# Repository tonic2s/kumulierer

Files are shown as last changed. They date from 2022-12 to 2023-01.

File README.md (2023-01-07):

# Kumulierer
## Description
Li-Ion battery charger with basic protection, usb-c input / 2-pin output &amp; power path

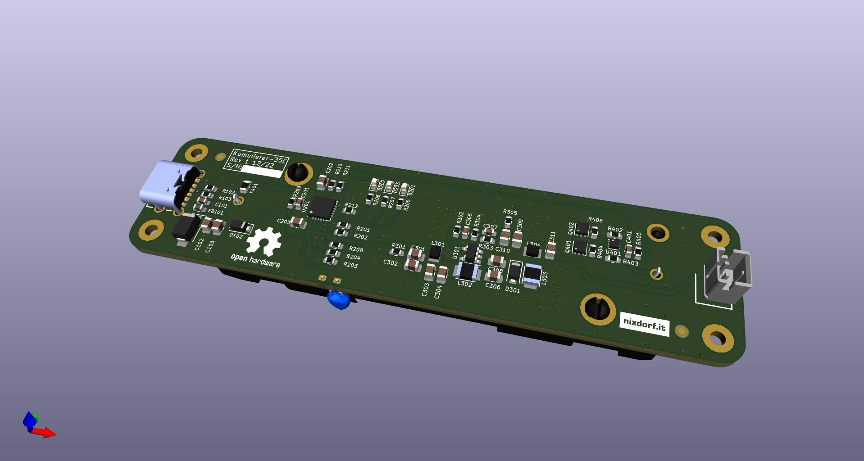
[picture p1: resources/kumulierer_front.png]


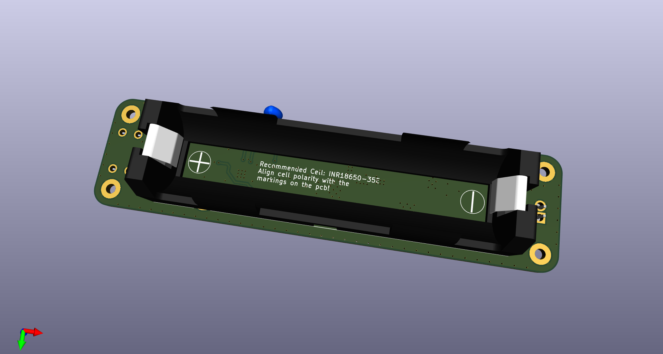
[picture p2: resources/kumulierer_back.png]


## Links
[Aisler Project](https://aisler.net/p/CNVPTRAD)

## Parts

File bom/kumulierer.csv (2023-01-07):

Source: | C:\Users\nixdo\Documents\E-Technik\kumulierer\kicad\kumulierer.kicad_sch
Date: | 07.01.2023 17:58:50
Tool: | Eeschema (6.0.6)
Generator: | C:\Program Files\KiCad\6.0\bin\scripting\plugins/bom_csv_grouped_by_value.py
Component Count: | 74
Individual Components:
Item | Qty | Reference(s) | Value | LibPart | Footprint | Datasheet | Mouser Part Nr.
 |  | BT401 | 18650-35E | Device:Battery_Cell | Parts_Library:1043_Battery_holder_18650 | https://www.mouser.de/datasheet/2/215/1043-745411.pdf | 534-1043
 |  | C101 | 100n | Device:C_Small | Capacitor_SMD:C_0603_1608Metric | https://www.mouser.de/datasheet/2/585/MLCC_Automotive-1837966.pdf | 187-CL10B104KO8WPNC
 |  | C102 | 10u | Device:C_Small | Capacitor_SMD:C_0805_2012Metric | https://www.mouser.de/datasheet/2/585/MLCC-1837944.pdf | 187-CL21A106KOQNNNE
 |  | C103 | 10u | Device:C_Small | Capacitor_SMD:C_0805_2012Metric | https://www.mouser.de/datasheet/2/585/MLCC-1837944.pdf | 187-CL21A106KOQNNNE
 |  | C201 | 100n | Device:C_Small | Capacitor_SMD:C_0603_1608Metric | https://www.mouser.de/datasheet/2/585/MLCC_Automotive-1837966.pdf | 187-CL10B104KO8WPNC
 |  | C202 | 10u | Device:C_Small | Capacitor_SMD:C_0805_2012Metric | https://www.mouser.de/datasheet/2/585/MLCC-1837944.pdf | 187-CL21A106KOQNNNE
 |  | C203 | 10u | Device:C_Small | Capacitor_SMD:C_0805_2012Metric | https://www.mouser.de/datasheet/2/585/MLCC-1837944.pdf | 187-CL21A106KOQNNNE
 |  | C301 | 10u | Device:C_Small | Capacitor_SMD:C_0805_2012Metric | https://www.mouser.de/datasheet/2/585/MLCC-1837944.pdf | 187-CL21A106KOQNNNE
 |  | C302 | 10u | Device:C_Small | Capacitor_SMD:C_0805_2012Metric | https://www.mouser.de/datasheet/2/585/MLCC-1837944.pdf | 187-CL21A106KOQNNNE
 |  | C303 | 10u | Device:C_Small | Capacitor_SMD:C_0805_2012Metric | https://www.mouser.de/datasheet/2/585/MLCC-1837944.pdf | 187-CL21A106KOQNNNE
 |  | C304 | 10u | Device:C_Small | Capacitor_SMD:C_0805_2012Metric | https://www.mouser.de/datasheet/2/585/MLCC-1837944.pdf | 187-CL21A106KOQNNNE
 |  | C305 | 100n | Device:C_Small | Capacitor_SMD:C_0603_1608Metric | https://www.mouser.de/datasheet/2/585/MLCC_Automotive-1837966.pdf | 187-CL10B104KO8WPNC
 |  | C306 | 10u | Device:C_Small | Capacitor_SMD:C_0805_2012Metric | https://www.mouser.de/datasheet/2/585/MLCC-1837944.pdf | 187-CL21A106KOQNNNE
 |  | C307 | 1n | Device:C_Small | Capacitor_SMD:C_0603_1608Metric | https://www.mouser.de/datasheet/2/585/MLCC-1837944.pdf | 187-CL10C102JB8NNND
 |  | C308 | 10u | Device:C_Small | Capacitor_SMD:C_0805_2012Metric | https://www.mouser.de/datasheet/2/585/MLCC-1837944.pdf | 187-CL21A106KOQNNNE
 |  | C309 | 10u | Device:C_Small | Capacitor_SMD:C_0805_2012Metric | https://www.mouser.de/datasheet/2/585/MLCC-1837944.pdf | 187-CL21A106KOQNNNE
 |  | C310 | 10u | Device:C_Small | Capacitor_SMD:C_0805_2012Metric | https://www.mouser.de/datasheet/2/585/MLCC-1837944.pdf | 187-CL21A106KOQNNNE
 |  | C311 | 10u | Device:C_Small | Capacitor_SMD:C_0805_2012Metric | https://www.mouser.de/datasheet/2/585/MLCC-1837944.pdf | 187-CL21A106KOQNNNE
 |  | C401 | 100n | Device:C_Small | Capacitor_SMD:C_0603_1608Metric | https://www.mouser.de/datasheet/2/585/MLCC_Automotive-1837966.pdf | 187-CL10B104KO8WPNC
 |  | D101 | SMA 5V | Device:D_Zener_Small | Diode_SMD:D_SMA | https://www.diodes.com/assets/Datasheets/ds18015.pdf | 621-SMAZ5V6-F
 |  | D102 | ACDBMS240-HF | Device:D_Schottky_Small | Diode_SMD:D_SOD-123F | https://www.mouser.de/datasheet/2/80/12030_20190322133442-2933606.pdf | 750-ACDBMS240-HF
 |  | D201 | RED | Device:LED_Small | LED_SMD:LED_0603_1608Metric | https://www.mouser.de/datasheet/2/445/150060RS75000-1715052.pdf | 710-150060RS75000
 |  | D202 | RED | Device:LED_Small | LED_SMD:LED_0603_1608Metric | https://www.mouser.de/datasheet/2/445/150060RS75000-1715052.pdf | 710-150060RS75000
 |  | D203 | RED | Device:LED_Small | LED_SMD:LED_0603_1608Metric | https://www.mouser.de/datasheet/2/445/150060RS75000-1715052.pdf | 710-150060RS75000
 |  | D301 | ACDBMS240-HF | Device:D_Schottky_Small | Diode_SMD:D_SOD-123F | https://www.mouser.de/datasheet/2/80/12030_20190322133442-2933606.pdf | 750-ACDBMS240-HF
 |  | F101 | 500mA 1206 | Device:Polyfuse_Small | Fuse:Fuse_1206_3216Metric | https://www.mouser.de/datasheet/2/447/SMD1206_1-1954982.pdf | 603-SMD1206B050TF/15
 |  | F401 | 6A | Device:Fuse_Small | Fuse:Fuse_0805_2012Metric | https://www.mouser.de/datasheet/2/643/ds-CP-c2f-series-1291054.pdf | 530-0686F6000-01
 |  | FB101 | 220 | Device:FerriteBead_Small | Inductor_SMD:L_0603_1608Metric | https://www.mouser.de/datasheet/2/54/mh-777565.pdf | 652-MH1608-221Y
 |  | FID101 | Fiducial | Mechanical:Fiducial | Fiducial:Fiducial_1mm_Mask2mm | ~
 |  | FID102 | Fiducial | Mechanical:Fiducial | Fiducial:Fiducial_1mm_Mask2mm | ~
 |  | H101 | M2 | Mechanical:MountingHole_Pad | MountingHole:MountingHole_2.2mm_M2_Pad | ~
 |  | H102 | M2 | Mechanical:MountingHole_Pad | MountingHole:MountingHole_2.2mm_M2_Pad | ~
 |  | H103 | M2 | Mechanical:MountingHole_Pad | MountingHole:MountingHole_2.2mm_M2_Pad | ~
 |  | H104 | M2 | Mechanical:MountingHole_Pad | MountingHole:MountingHole_2.2mm_M2_Pad | ~
 |  | J101 | USB4125-GF-A | Connector:USB_C_Receptacle_USB2.0 | Parts_Library:USB4125GFA | https://www.mouser.de/datasheet/2/837/USB4125-2888141.pdf | 640-USB4125-GF-A
 |  | J102 | 6-440054-2 | Connector_Generic:Conn_01x02 | Parts_Library:6-440054-2 2 Pin Header | https://www.te.com/commerce/DocumentDelivery/DDEController?Action=srchrtrv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 | 6-440054-2
 |  | L301 | 470nH | Device:L_Small | Parts_Library:IND_0806_2016 | https://www.mouser.de/datasheet/2/396/wound10_e-1396630.pdf | 963-MAKK2016TR47M
 |  | L302 | 3.3uH | Device:L_Small | Inductor_SMD:L_TDK_NLV32_3.2x2.5mm | https://www.mouser.de/datasheet/2/54/SRP3212A-3011944.pdf | 652-SRP3212A-3R3M
 |  | L303 | 3.3uH | Device:L_Small | Inductor_SMD:L_TDK_NLV32_3.2x2.5mm | https://www.mouser.de/datasheet/2/54/SRP3212A-3011944.pdf | 652-SRP3212A-3R3M
 |  | L304 | 470nH | Device:L_Small | Parts_Library:IND_0806_2016 | https://www.mouser.de/datasheet/2/396/wound10_e-1396630.pdf | 963-MAKK2016TR47M
 |  | Q401 | CSD17313Q2 | Transistor_FET:CSD17313Q2 | Package_SON:Texas_DQK | http://www.ti.com/lit/ds/symlink/csd17313q2.pdf | 595-CSD17313Q2
 |  | Q402 | CSD17313Q2 | Transistor_FET:CSD17313Q2 | Package_SON:Texas_DQK | http://www.ti.com/lit/ds/symlink/csd17313q2.pdf | 595-CSD17313Q2
 |  | R102 | 5k1 | Device:R_Small | Resistor_SMD:R_0603_1608Metric | https://www.mouser.de/datasheet/2/447/PYu_RC_Group_51_RoHS_L_11-1984063.pdf | 603-RC0603JR-075K1L
 |  | R103 | 5k1 | Device:R_Small | Resistor_SMD:R_0603_1608Metric | https://www.mouser.de/datasheet/2/447/PYu_RC_Group_51_RoHS_L_11-1984063.pdf | 603-RC0603JR-075K1L
 |  | R201 | 0 | Device:R_Small | Resistor_SMD:R_0603_1608Metric | https://www.mouser.de/datasheet/2/447/PYu_RC_Group_51_RoHS_L_11-1984063.pdf | 603-RC0603JR-070RL
 |  | R202 | 0 | Device:R_Small | Resistor_SMD:R_0603_1608Metric | https://www.mouser.de/datasheet/2/447/PYu_RC_Group_51_RoHS_L_11-1984063.pdf | 603-RC0603JR-070RL
 |  | R203 | 330k | Device:R_Small | Resistor_SMD:R_0603_1608Metric | https://www.mouser.de/datasheet/2/447/PYu_RC_Group_51_RoHS_L_11-1984063.pdf | 603-RC0603FR-13330KL
 |  | R204 | 110k | Device:R_Small | Resistor_SMD:R_0603_1608Metric | https://www.mouser.de/datasheet/2/447/PYu_RC_Group_51_RoHS_L_11-1984063.pdf | 603-RC0603JR-13110KL
 |  | R205 | 1k | Device:R_Small | Resistor_SMD:R_0603_1608Metric | https://www.mouser.de/datasheet/2/447/PYu_RC_Group_51_RoHS_L_11-1984063.pdf | 603-RC0603JR-071KL
 |  | R206 | 1k | Device:R_Small | Resistor_SMD:R_0603_1608Metric | https://www.mouser.de/datasheet/2/447/PYu_RC_Group_51_RoHS_L_11-1984063.pdf | 603-RC0603JR-071KL
 |  | R207 | 1k | Device:R_Small | Resistor_SMD:R_0603_1608Metric | https://www.mouser.de/datasheet/2/447/PYu_RC_Group_51_RoHS_L_11-1984063.pdf | 603-RC0603JR-071KL
 |  | R208 | 1k | Device:R_Small | Resistor_SMD:R_0603_1608Metric | https://www.mouser.de/datasheet/2/447/PYu_RC_Group_51_RoHS_L_11-1984063.pdf | 603-RC0603JR-071KL
 |  | R209 | 1k | Device:R_Small | Resistor_SMD:R_0603_1608Metric | https://www.mouser.de/datasheet/2/447/PYu_RC_Group_51_RoHS_L_11-1984063.pdf | 603-RC0603JR-071KL
 |  | R210 | 2k2 | Device:R_Small | Resistor_SMD:R_0603_1608Metric | https://www.mouser.de/datasheet/2/447/PYu_RC_Group_51_RoHS_L_11-1984063.pdf | 603-RC0603FR-072K2L
 |  | R211 | 22k | Device:R_Small | Resistor_SMD:R_0603_1608Metric | https://www.mouser.de/datasheet/2/447/PYu_RC_Group_51_RoHS_L_11-1984063.pdf | 603-RC0603JR-0722KL
 |  | R212 | 1k | Device:R_Small | Resistor_SMD:R_0603_1608Metric | https://www.mouser.de/datasheet/2/447/PYu_RC_Group_51_RoHS_L_11-1984063.pdf | 603-RC0603JR-071KL
 |  | R213 | 1k | Device:R_Small | Resistor_SMD:R_0603_1608Metric | https://www.mouser.de/datasheet/2/447/PYu_RC_Group_51_RoHS_L_11-1984063.pdf | 603-RC0603JR-071KL
 |  | R214 | 10k | Device:R_Small | Resistor_SMD:R_0603_1608Metric | https://www.mouser.de/datasheet/2/447/PYu_RC_Group_51_RoHS_L_11-1984063.pdf | 603-RC0603FR-0710KL
 |  | R301 | 1 | Device:R_Small | Resistor_SMD:R_0603_1608Metric | https://www.mouser.de/datasheet/2/447/PYu_RC_Group_51_RoHS_L_11-1984063.pdf | 603-RC0603JR-071RL
 |  | R302 | 10k | Device:R_Small | Resistor_SMD:R_0603_1608Metric | https://www.mouser.de/datasheet/2/447/PYu_RC_Group_51_RoHS_L_11-1984063.pdf | 603-RC0603FR-0710KL
 |  | R303 | 30k | Device:R_Small | Resistor_SMD:R_0603_1608Metric | https://www.mouser.de/datasheet/2/315/AOA0000C304-1149620.pdf | 667-ERJ-3EKF3002V
 |  | R304 | 10k | Device:R_Small | Resistor_SMD:R_0603_1608Metric | https://www.mouser.de/datasheet/2/447/PYu_RC_Group_51_RoHS_L_11-1984063.pdf | 603-RC0603FR-0710KL
 |  | R305 | 1 | Device:R_Small | Resistor_SMD:R_0603_1608Metric | https://www.mouser.de/datasheet/2/447/PYu_RC_Group_51_RoHS_L_11-1984063.pdf | 603-RC0603JR-071RL
 |  | R306 | 1M | Device:R_Small | Resistor_SMD:R_0603_1608Metric | https://www.mouser.de/datasheet/2/447/PYu_RC_Group_51_RoHS_L_11-1984063.pdf | 603-RC0603FR-071ML
 |  | R401 | 330 | Device:R_Small | Resistor_SMD:R_0603_1608Metric | https://www.mouser.de/datasheet/2/447/PYu_RC_Group_51_RoHS_L_11-1984063.pdf | 603-RC0603FR-13330RL
 |  | R402 | 2k2 | Device:R_Small | Resistor_SMD:R_0603_1608Metric | https://www.mouser.de/datasheet/2/447/PYu_RC_Group_51_RoHS_L_11-1984063.pdf | 603-RC0603FR-072K2L
 |  | R403 | 0 | Device:R_Small | Resistor_SMD:R_0603_1608Metric | https://www.mouser.de/datasheet/2/447/PYu_RC_Group_51_RoHS_L_11-1984063.pdf | 603-RC0603JR-070RL
 |  | R404 | 5.1M | Device:R_Small | Resistor_SMD:R_0603_1608Metric | https://www.mouser.de/datasheet/2/447/PYu_AC_51_RoHS_L_9-3005297.pdf | 603-AC0603FR-075M1L
 |  | R405 | 5.1M | Device:R_Small | Resistor_SMD:R_0603_1608Metric | https://www.mouser.de/datasheet/2/447/PYu_AC_51_RoHS_L_9-3005297.pdf | 603-AC0603FR-075M1L
 |  | SW101 | DS04-254-2-02BK-SMT | Switch:SW_DIP_x02 | Footprints:SW_DS04-254-2-02BK-SMT | https://www.mouser.de/datasheet/2/670/ds04_254_smt-1777718.pdf | 490-DS04254202BK-SMT
 |  | TH201 | 10k | Device:Thermistor_NTC | Parts_Library:NRL1104J3380B1F | https://www.eaton.com/content/dam/eaton/products/electronic-components/resources/data-sheet/eaton-nrl-epoxy-sealed-radial-lead-ntc-thermistor-data-sheet-elx11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 | 504-NRL1104J3380B1F
 |  | U201 | MCP73871-2CC | Battery_Management:MCP73871-2CC | Package_DFN_QFN:QFN-20-1EP_4x4mm_P0.5mm_EP2.5x2.5mm | http://www.mouser.com/ds/2/268/22090a-52174.pdf
 |  | U301 | LMR62421XMF | Regulator_Switching:LMR62421XMF | Package_TO_SOT_SMD:SOT-23-5 | http://www.ti.com/lit/ds/symlink/lmr62421.pdf
 |  | U401 | BQ29717 | Battery_Management:BQ297xy | Package_SON:WSON-6_1.5x1.5mm_P0.5mm | http://www.ti.com/lit/ds/symlink/bq2970.pdf | 595-BQ29717DSER
Collated Components:
Item | Qty | Reference(s) | Value | LibPart | Footprint | Datasheet | Mouser Part Nr.
1 | 1 | BT401 | 18650-35E | Device:Battery_Cell | Parts_Library:1043_Battery_holder_18650 | https://www.mouser.de/datasheet/2/215/1043-745411.pdf | 534-1043
2 | 4 | C101, C201, C305, C401 | 100n | Device:C_Small | Capacitor_SMD:C_0603_1608Metric | https://www.mouser.de/datasheet/2/585/MLCC_Automotive-1837966.pdf | 187-CL10B104KO8WPNC
3 | 13 | C102, C103, C202, C203, C301, C302, C303, C304, C306, C308, C309, C310, C311 | 10u | Device:C_Small | Capacitor_SMD:C_0805_2012Metric | https://www.mouser.de/datasheet/2/585/MLCC-1837944.pdf | 187-CL21A106KOQNNNE
4 | 1 | C307 | 1n | Device:C_Small | Capacitor_SMD:C_0603_1608Metric | https://www.mouser.de/datasheet/2/585/MLCC-1837944.pdf | 187-CL10C102JB8NNND
5 | 1 | D101 | SMA 5V | Device:D_Zener_Small | Diode_SMD:D_SMA | https://www.diodes.com/assets/Datasheets/ds18015.pdf | 621-SMAZ5V6-F
6 | 2 | D102, D301 | ACDBMS240-HF | Device:D_Schottky_Small | Diode_SMD:D_SOD-123F | https://www.mouser.de/datasheet/2/80/12030_20190322133442-2933606.pdf | 750-ACDBMS240-HF
7 | 3 | D201, D202, D203 | RED | Device:LED_Small | LED_SMD:LED_0603_1608Metric | https://www.mouser.de/datasheet/2/445/150060RS75000-1715052.pdf | 710-150060RS75000
8 | 1 | F101 | 500mA 1206 | Device:Polyfuse_Small | Fuse:Fuse_1206_3216Metric | https://www.mouser.de/datasheet/2/447/SMD1206_1-1954982.pdf | 603-SMD1206B050TF/15
9 | 1 | F401 | 6A | Device:Fuse_Small | Fuse:Fuse_0805_2012Metric | https://www.mouser.de/datasheet/2/643/ds-CP-c2f-series-1291054.pdf | 530-0686F6000-01
10 | 1 | FB101 | 220 | Device:FerriteBead_Small | Inductor_SMD:L_0603_1608Metric | https://www.mouser.de/datasheet/2/54/mh-777565.pdf | 652-MH1608-221Y
11 | 2 | FID101, FID102 | Fiducial | Mechanical:Fiducial | Fiducial:Fiducial_1mm_Mask2mm | ~
12 | 4 | H101, H102, H103, H104 | M2 | Mechanical:MountingHole_Pad | MountingHole:MountingHole_2.2mm_M2_Pad | ~
13 | 1 | J101 | USB4125-GF-A | Connector:USB_C_Receptacle_USB2.0 | Parts_Library:USB4125GFA | https://www.mouser.de/datasheet/2/837/USB4125-2888141.pdf | 640-USB4125-GF-A
14 | 1 | J102 | 6-440054-2 | Connector_Generic:Conn_01x02 | Parts_Library:6-440054-2 2 Pin Header | https://www.te.com/commerce/DocumentDelivery/DDEController?Action=srchrtrv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 | 6-440054-2
15 | 2 | L301, L304 | 470nH | Device:L_Small | Parts_Library:IND_0806_2016 | https://www.mouser.de/datasheet/2/396/wound10_e-1396630.pdf | 963-MAKK2016TR47M
16 | 2 | L302, L303 | 3.3uH | Device:L_Small | Inductor_SMD:L_TDK_NLV32_3.2x2.5mm | https://www.mouser.de/datasheet/2/54/SRP3212A-3011944.pdf | 652-SRP3212A-3R3M
17 | 2 | Q401, Q402 | CSD17313Q2 | Transistor_FET:CSD17313Q2 | Package_SON:Texas_DQK | http://www.ti.com/lit/ds/symlink/csd17313q2.pdf | 595-CSD17313Q2
18 | 2 | R102, R103 | 5k1 | Device:R_Small | Resistor_SMD:R_0603_1608Metric | https://www.mouser.de/datasheet/2/447/PYu_RC_Group_51_RoHS_L_11-1984063.pdf | 603-RC0603JR-075K1L
19 | 3 | R201, R202, R403 | 0 | Device:R_Small | Resistor_SMD:R_0603_1608Metric | https://www.mouser.de/datasheet/2/447/PYu_RC_Group_51_RoHS_L_11-1984063.pdf | 603-RC0603JR-070RL
20 | 1 | R203 | 330k | Device:R_Small | Resistor_SMD:R_0603_1608Metric | https://www.mouser.de/datasheet/2/447/PYu_RC_Group_51_RoHS_L_11-1984063.pdf | 603-RC0603FR-13330KL
21 | 1 | R204 | 110k | Device:R_Small | Resistor_SMD:R_0603_1608Metric | https://www.mouser.de/datasheet/2/447/PYu_RC_Group_51_RoHS_L_11-1984063.pdf | 603-RC0603JR-13110KL
22 | 7 | R205, R206, R207, R208, R209, R212, R213 | 1k | Device:R_Small | Resistor_SMD:R_0603_1608Metric | https://www.mouser.de/datasheet/2/447/PYu_RC_Group_51_RoHS_L_11-1984063.pdf | 603-RC0603JR-071KL
23 | 2 | R210, R402 | 2k2 | Device:R_Small | Resistor_SMD:R_0603_1608Metric | https://www.mouser.de/datasheet/2/447/PYu_RC_Group_51_RoHS_L_11-1984063.pdf | 603-RC0603FR-072K2L
24 | 1 | R211 | 22k | Device:R_Small | Resistor_SMD:R_0603_1608Metric | https://www.mouser.de/datasheet/2/447/PYu_RC_Group_51_RoHS_L_11-1984063.pdf | 603-RC0603JR-0722KL
25 | 3 | R214, R302, R304 | 10k | Device:R_Small | Resistor_SMD:R_0603_1608Metric | https://www.mouser.de/datasheet/2/447/PYu_RC_Group_51_RoHS_L_11-1984063.pdf | 603-RC0603FR-0710KL
26 | 2 | R301, R305 | 1 | Device:R_Small | Resistor_SMD:R_0603_1608Metric | https://www.mouser.de/datasheet/2/447/PYu_RC_Group_51_RoHS_L_11-1984063.pdf | 603-RC0603JR-071RL
27 | 1 | R303 | 30k | Device:R_Small | Resistor_SMD:R_0603_1608Metric | https://www.mouser.de/datasheet/2/315/AOA0000C304-1149620.pdf | 667-ERJ-3EKF3002V
28 | 1 | R306 | 1M | Device:R_Small | Resistor_SMD:R_0603_1608Metric | https://www.mouser.de/datasheet/2/447/PYu_RC_Group_51_RoHS_L_11-1984063.pdf | 603-RC0603FR-071ML
29 | 1 | R401 | 330 | Device:R_Small | Resistor_SMD:R_0603_1608Metric | https://www.mouser.de/datasheet/2/447/PYu_RC_Group_51_RoHS_L_11-1984063.pdf | 603-RC0603FR-13330RL
30 | 2 | R404, R405 | 5.1M | Device:R_Small | Resistor_SMD:R_0603_1608Metric | https://www.mouser.de/datasheet/2/447/PYu_AC_51_RoHS_L_9-3005297.pdf | 603-AC0603FR-075M1L
31 | 1 | SW101 | DS04-254-2-02BK-SMT | Switch:SW_DIP_x02 | Footprints:SW_DS04-254-2-02BK-SMT | https://www.mouser.de/datasheet/2/670/ds04_254_smt-1777718.pdf | 490-DS04254202BK-SMT
32 | 1 | TH201 | 10k | Device:Thermistor_NTC | Parts_Library:NRL1104J3380B1F | https://www.eaton.com/content/dam/eaton/products/electronic-components/resources/data-sheet/eaton-nrl-epoxy-sealed-radial-lead-ntc-thermistor-data-sheet-elx11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 | 504-NRL1104J3380B1F
33 | 1 | U201 | MCP73871-2CC | Battery_Management:MCP73871-2CC | Package_DFN_QFN:QFN-20-1EP_4x4mm_P0.5mm_EP2.5x2.5mm | http://www.mouser.com/ds/2/268/22090a-52174.pdf
34 | 1 | U301 | LMR62421XMF | Regulator_Switching:LMR62421XMF | Package_TO_SOT_SMD:SOT-23-5 | http://www.ti.com/lit/ds/symlink/lmr62421.pdf
35 | 1 | U401 | BQ29717 | Battery_Management:BQ297xy | Package_SON:WSON-6_1.5x1.5mm_P0.5mm | http://www.ti.com/lit/ds/symlink/bq2970.pdf | 595-BQ29717DSER

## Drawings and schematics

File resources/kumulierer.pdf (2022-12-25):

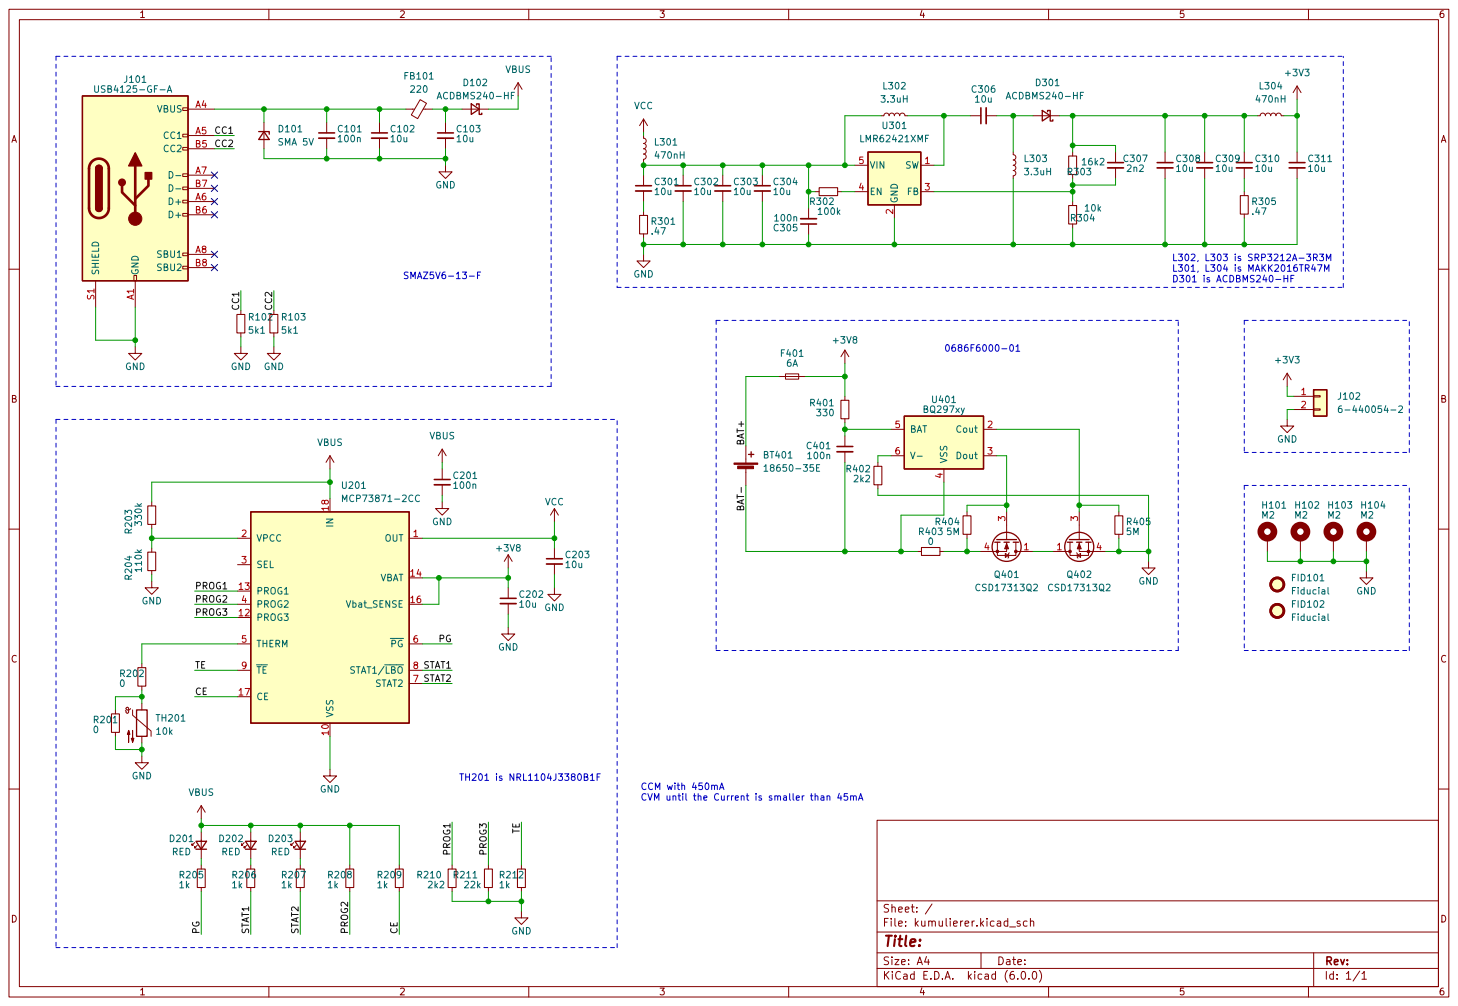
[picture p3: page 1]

L302, L303 is SRP3212A-3R3M L301, L304 is MAKK2016TR47M D301 is ACDBMS240-HF

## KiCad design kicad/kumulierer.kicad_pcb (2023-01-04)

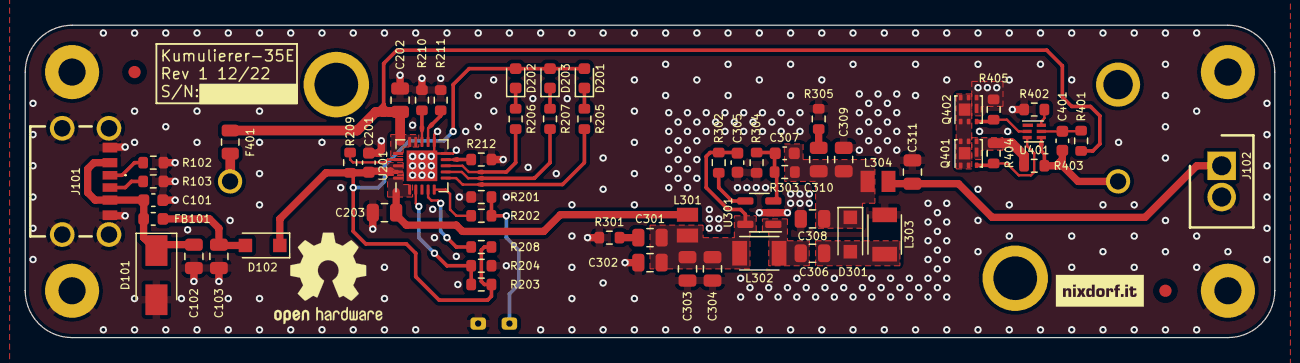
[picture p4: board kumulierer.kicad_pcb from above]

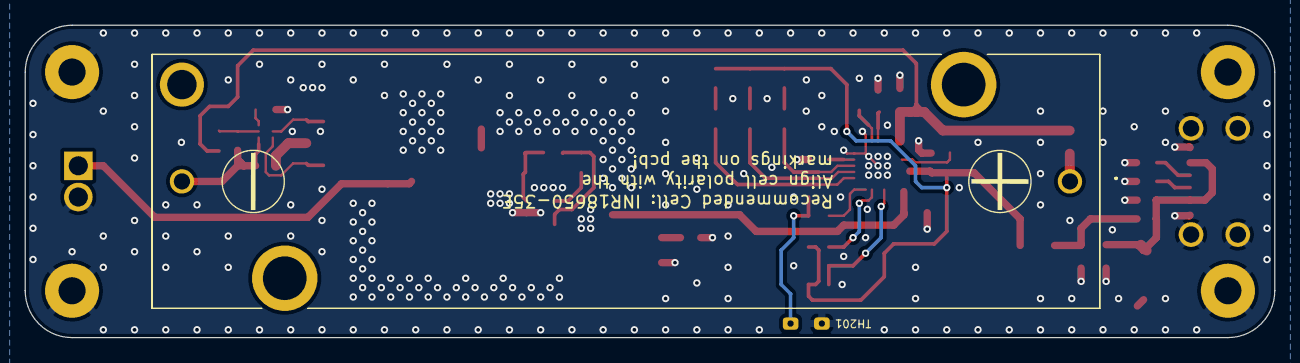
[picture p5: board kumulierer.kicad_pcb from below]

Board: 2 copper layers, 101.6 x 25.4 mm, 69 parts (2 on the bottom side), 39 nets.

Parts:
BT401: 18650-35E; 1043_Battery_holder_18650
C101, C201, C305, C401: 100n; C_0603_1608Metric
C102, C103, C202, C203, C301, C302, C303, C304, C306, C308, C309, C310, C311: 10u; C_0805_2012Metric
C307: 2n2; C_0603_1608Metric
D101: SMA 5V; D_SMA
D102, D301: ACDBMS240-HF; D_SOD-123F
D201, D202, D203: RED; LED_0603_1608Metric
F401: 6A; Fuse_0805_2012Metric
FB101: 220; L_0603_1608Metric
FID101, FID102: Fiducial; Fiducial_1mm_Mask2mm
H101, H102, H103, H104: M2; MountingHole_2.2mm_M2_Pad
J101: USB4125-GF-A; USB4125GFA
J102: 6-440054-2; 6-440054-2 2 Pin Header
L301, L304: 470nH; IND_0806_2016
L302, L303: 3.3uH; L_TDK_NLV32_3.2x2.5mm
Q401, Q402: CSD17313Q2; Texas_DQK
R102, R103: 5k1; R_0603_1608Metric
R201, R202, R403: 0; R_0603_1608Metric
R203: 330k; R_0603_1608Metric
R204: 110k; R_0603_1608Metric
R205, R206, R207, R208, R209, R212: 1k; R_0603_1608Metric
R210, R402: 2k2; R_0603_1608Metric
R211: 22k; R_0603_1608Metric
R301, R305: .47; R_0603_1608Metric
R302: 100k; R_0603_1608Metric
R303: 16k2; R_0603_1608Metric
R304: 10k; R_0603_1608Metric
R401: 330; R_0603_1608Metric
R404, R405: 5M; R_0603_1608Metric
TH201: 10k; NRL1104J3380B1F
U201: MCP73871-2CC; QFN-20-1EP_4x4mm_P0.5mm_EP2.5x2.5mm
U301: LMR62421XMF; SOT-23-5
U401: BQ297xy; WSON-6_1.5x1.5mm_P0.5mm

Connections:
+3V3: C311.1, J102.1, L304.2
+3V8: C202.1, F401.2, R401.2, U201.14 (VBAT), U201.15 (VBAT), U201.16 (Vbat_SENSE)
/BAT+: BT401.1 (+), F401.1
/BAT-: BT401.2 (-), C401.2, R403.1, U401.4 (VSS)
/CC1: J101.A5 (CC1), R102.1
/CC2: J101.B5 (CC2), R103.1
/CE: R209.2, U201.17 (CE)
/PG: R205.2, U201.6 (~PG)
/PROG1: R210.2, U201.13 (PROG1)
/PROG2: R208.2, U201.4 (PROG2)
/PROG3: R211.2, U201.12 (PROG3)
/STAT1: R206.2, U201.8 (STAT1/~LBO)
/STAT2: R207.2, U201.7 (STAT2)
/TE: R212.1, U201.9 (~TE)
GND: C101.2, C102.2, C103.2, C201.2, C202.2, C203.2, C302.2, C303.2, C304.2, C305.1, C308.2, C309.2, C311.2, D101.2 (A), H101.1, H102.1, H103.1, H104.1, J101.A12 (GND), J101.B12 (GND), J101.S1 (SHIELD), J102.2, L303.2, Q402.4 (S), Q402.7 (S), R102.2, R103.2, R201.2, R204.1, R210.1, R211.1, R212.2, R301.2, R304.1, R305.2, R402.1, R405.2, TH201.2, U201.10 (VSS), U201.11 (VSS), U201.21 (VSS), U301.2 (GND)
unnamed: C101.1, C102.1, D101.1 (K), FB101.1, J101.A9 (VBUS), J101.B9 (VBUS)
unnamed: C103.1, D102.2 (A), FB101.2
unnamed: C301.1, C302.1, C303.1, C304.1, C305.2, L301.2, L302.1, R302.1, U301.5 (VIN)
unnamed: C301.2, R301.1
unnamed: C306.1, L302.2, U301.1 (SW)
unnamed: C306.2, D301.2 (A), L303.1
unnamed: C307.1, C308.1, C309.1, C310.1, D301.1 (K), L304.1, R303.2
unnamed: C307.2, R303.1, R304.2, U301.3 (FB)
unnamed: C310.2, R305.1
unnamed: C401.1, R401.1, U401.5 (BAT)
unnamed: D201.1 (K), R205.1
unnamed: D202.1 (K), R206.1
unnamed: D203.1 (K), R207.1
unnamed: Q401.1 (D), Q401.2 (D), Q401.5 (D), Q401.6 (D), Q401.8 (D), Q402.1 (D), Q402.2 (D), Q402.5 (D), Q402.6 (D), Q402.8 (D)
unnamed: Q401.3 (G), R404.1, U401.3 (Dout)
unnamed: Q401.4 (S), Q401.7 (S), R403.2, R404.2
unnamed: Q402.3 (G), R405.1, U401.2 (Cout)
unnamed: R201.1, R202.2, TH201.1
unnamed: R202.1, U201.5 (THERM)
unnamed: R203.1, R204.2, U201.2 (VPCC)
unnamed: R302.2, U301.4 (EN)
unnamed: R402.2, U401.6 (V-)
VBUS: C201.1, D102.1 (K), D201.2 (A), D202.2 (A), D203.2 (A), R203.2, R208.1, R209.1, U201.18 (IN), U201.19 (IN)
VCC: C203.1, L301.1, U201.1 (OUT), U201.20 (OUT)

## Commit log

2023-01-04 Added .gitIgnore & updated files
    [kumulierer.kicad_pcb]
2023-01-07 Add interactive bom; fix schematic & pcb
    [kumulierer.csv, kumulierer.kicad_sch]
